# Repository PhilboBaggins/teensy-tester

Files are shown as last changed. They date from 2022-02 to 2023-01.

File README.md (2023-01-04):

Teensy Tester
=============

Test most (not all) of the GPIO pins on a Teensy LC board. Created so I could easily check the I/O pins were working before using the Teensy LC in an important project.

This tester board basically works by grouping the Teensy LC GPIO pins into pairs and linking them together through a resistor. One pin can then be made an output and driven to a known voltage (high or low) and this output verified by reading the voltage on the other pin in the pair. The roles of the pins in the pair can then be swapped to test I/O in the other direction.

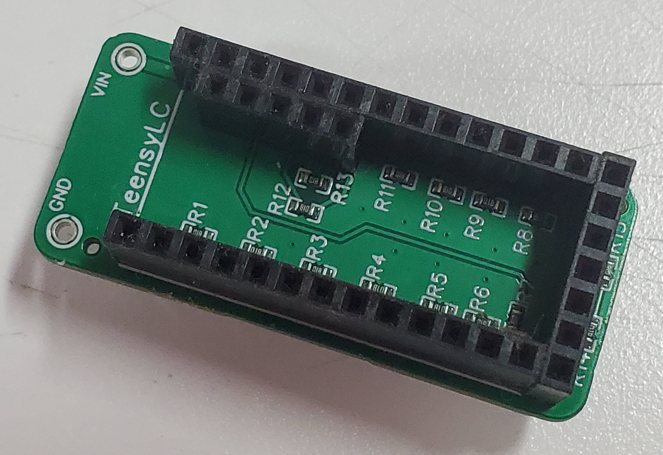
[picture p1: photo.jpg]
Photo of assembled board


Licence
-------

Copyright © 2022 Phil Baldwin

This work is licensed under a Creative Commons Attribution-ShareAlike 4.0 International License.

You should have received a copy of the license along with this work. If not, see <http://creativecommons.org/licenses/by-sa/4.0/>.

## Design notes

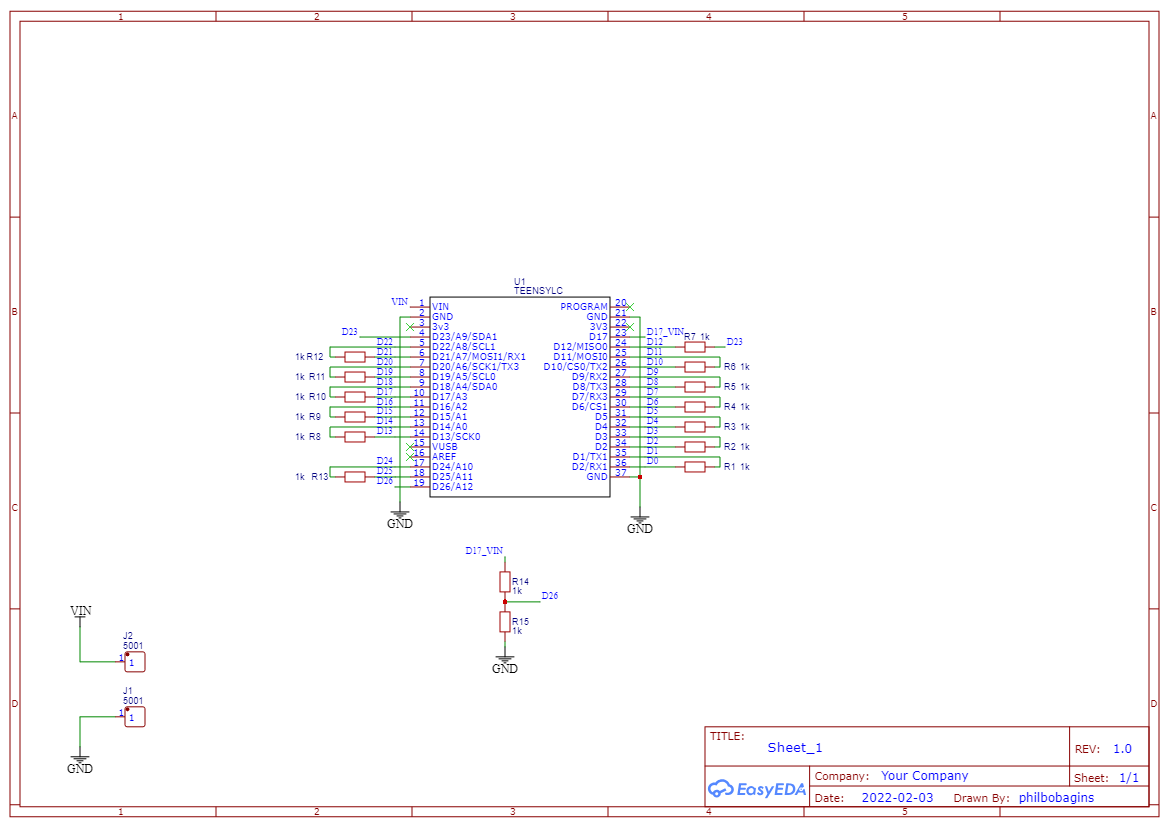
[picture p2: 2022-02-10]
Exports-v1.0/Schematic.png

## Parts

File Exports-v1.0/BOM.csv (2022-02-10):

ID | Name | Designator | Footprint | Quantity | Manufacturer Part | Manufacturer | Supplier | Supplier Part | Price
1 | TEENSYLC | U1 | TEENSYLC | 1
2 | 1k | R1,R2,R3,R4,R5,R6,R7,R8,R9,R10,R11,R12,R13,R14,R15 | R0603 | 15
3 | 5001 | GND,VIN | TEST-TH_BD2.54-P1.39 | 2 | 5001 | Keystone | LCSC | C238122 | 0.235

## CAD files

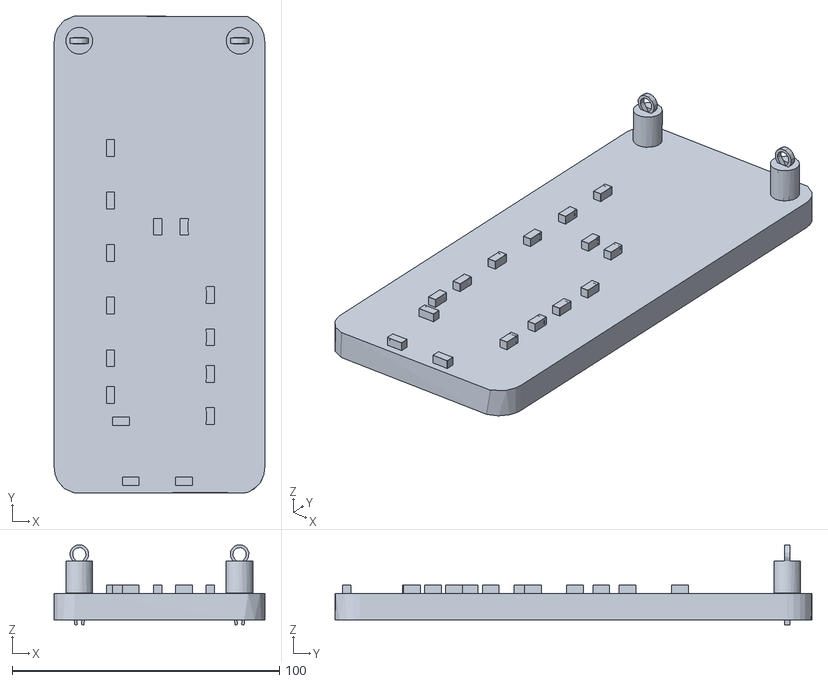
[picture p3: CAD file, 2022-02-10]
Exports-v1.0/3D model/OBJ_PCB_Teensy Tester.obj
78.8 x 178.6 x 29.9

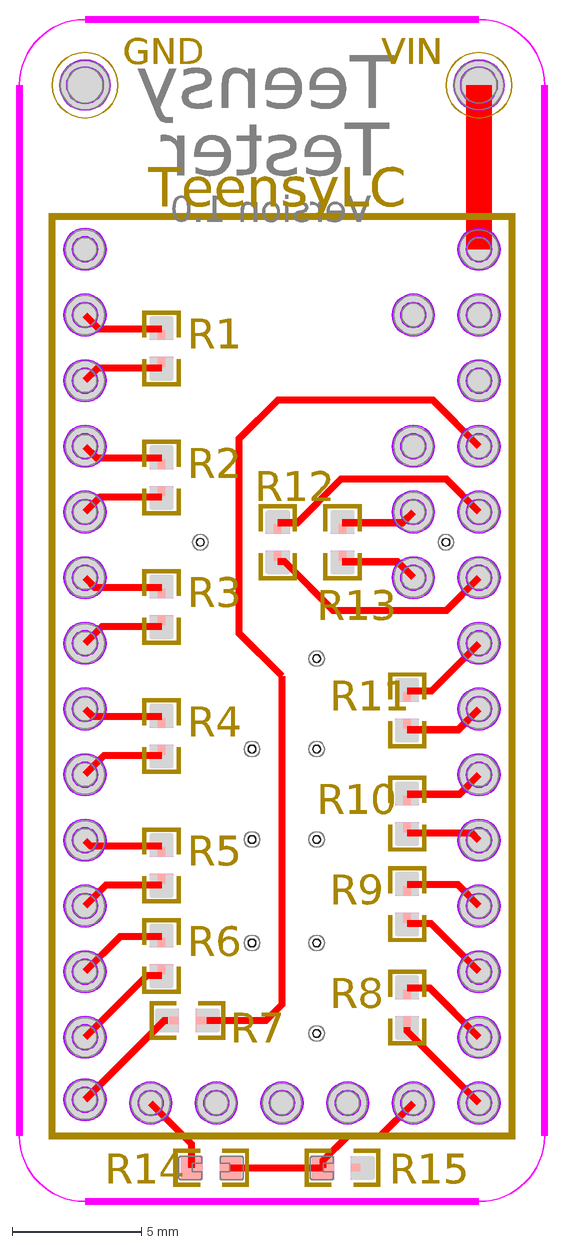
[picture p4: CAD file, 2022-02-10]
Exports-v1.0/PCB.dxf
Teensy
Tester
Version 1.0
TeensyLC
R1
R2
R3
R4
R5
R6
R7
R8
R9
R10
R11
R12
R13
R14
R15
GND
VIN

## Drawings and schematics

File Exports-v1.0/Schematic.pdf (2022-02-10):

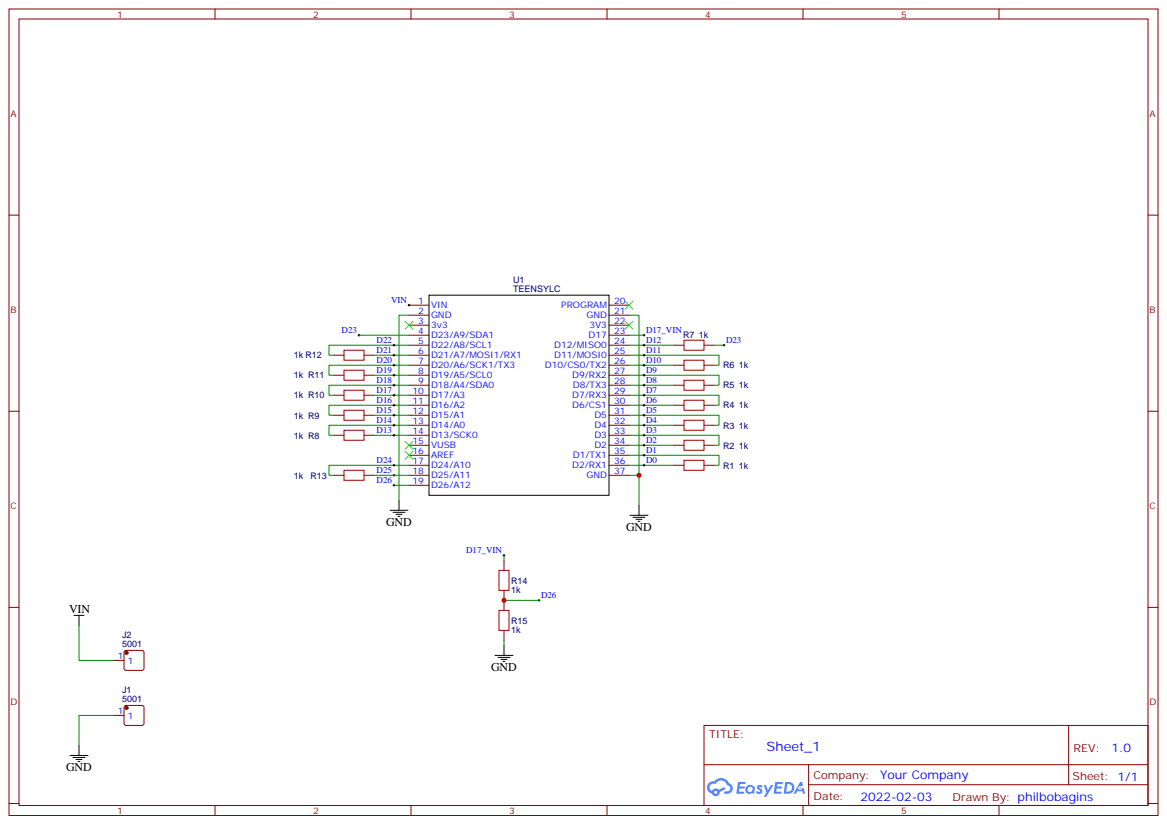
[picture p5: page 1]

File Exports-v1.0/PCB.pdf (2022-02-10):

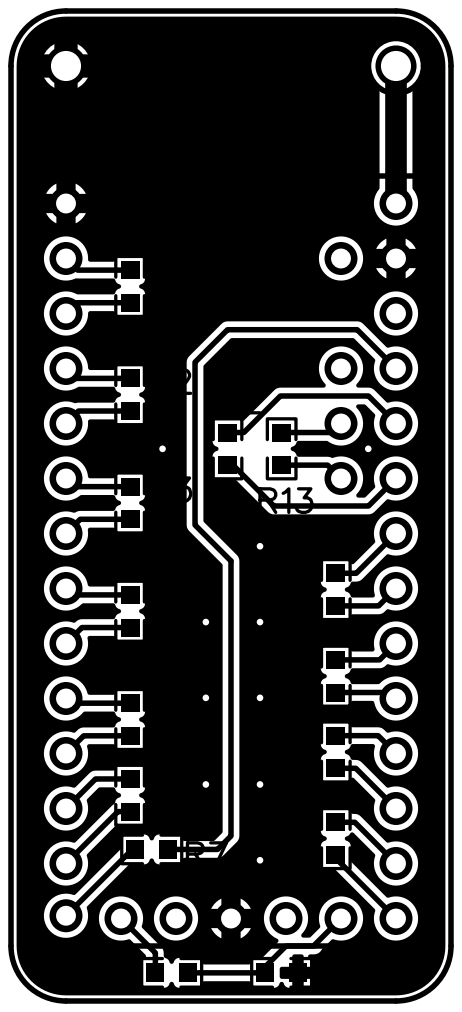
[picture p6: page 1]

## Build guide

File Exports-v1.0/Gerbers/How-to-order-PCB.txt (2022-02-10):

How to Order PCB

Please refer to:
https://docs.easyeda.com/en/PCB/Order-PCB

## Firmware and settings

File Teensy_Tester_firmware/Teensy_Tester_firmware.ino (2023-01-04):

const int PIN_PAIRS[][2] = {
  {  0,  1 },
  {  2,  3 },
  {  4,  5 },
  {  6,  7 },
  {  8,  9 },
  { 10, 11 },
  { 13, 14 },
  { 15, 16 },
  { 17, 18 },
  { 19, 20 },
  { 21, 22 },

  // ?????????
  //{ 12, 23 },
  //{ 17, 26 },
};

const size_t NUM_PAIRS = sizeof(PIN_PAIRS) / sizeof(int) / 2;

bool testIO(int outputPin, int inputPin)
{
    const int DELAY_MS = 1;

    pinMode(outputPin, OUTPUT);
    pinMode(inputPin, INPUT);
    delay(DELAY_MS);

    digitalWrite(outputPin, LOW);
    delay(DELAY_MS);
    if (digitalRead(inputPin) != LOW)
    {
        Serial.println("Low fail");
        return false;
    }

    digitalWrite(outputPin, HIGH);
    delay(DELAY_MS);
    if (digitalRead(inputPin) != HIGH)
    {
        Serial.println("High fail");
        return false;
    }

    Serial.println("Success");
    return true;
}

bool testPair(int pairIdx)
{
    int pinA = PIN_PAIRS[pairIdx][0];
    int pinB = PIN_PAIRS[pairIdx][1];

    Serial.print("Testing pair #");
    Serial.print(pairIdx);
    Serial.print(" ... ");
    if (testIO(pinA, pinB) == false)
        return false;

    Serial.print("Testing pair #");
    Serial.print(pairIdx);
    Serial.print(" ... ");
    return testIO(pinB, pinA);
}

bool doTest()
{
    int numFailures = 0;
    for (size_t i = 0; i < NUM_PAIRS; i++)
    {
        if (testPair(i) == false)
            numFailures++;
    }

    Serial.print("There were ");
    Serial.print(numFailures);
    Serial.println(" failures");
    Serial.println();

    return numFailures == 0;
}

void setup()
{

}

void loop()
{
    doTest();
    delay(1000);
}
